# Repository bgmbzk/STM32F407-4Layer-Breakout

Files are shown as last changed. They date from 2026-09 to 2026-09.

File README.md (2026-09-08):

# STM32F407VGTx Yüksek Performanslı 4 Katmanlı PCB Geliştirme Kartı

Bu depo, **STM32F407VGT6** ARM Cortex-M4 mikrodenetleyicisi etrafında tasarlanmış, 4 katmanlı özgün bir basılı devre kartının (PCB) tasarım dosyalarını içermektedir.

Bu projenin temel amacı; gerçek zamanlı kontrol sistemleri, robotik uygulamalar ve yüksek kararlılık gerektiren gömülü sistem prototipleri için endüstriyel standartlarda, gürültüye dayanıklı ve güvenilir bir donanım platformu oluşturmaktır.

---

## Görseller

### 1. 3D Model Görünümü (3D Viewer)
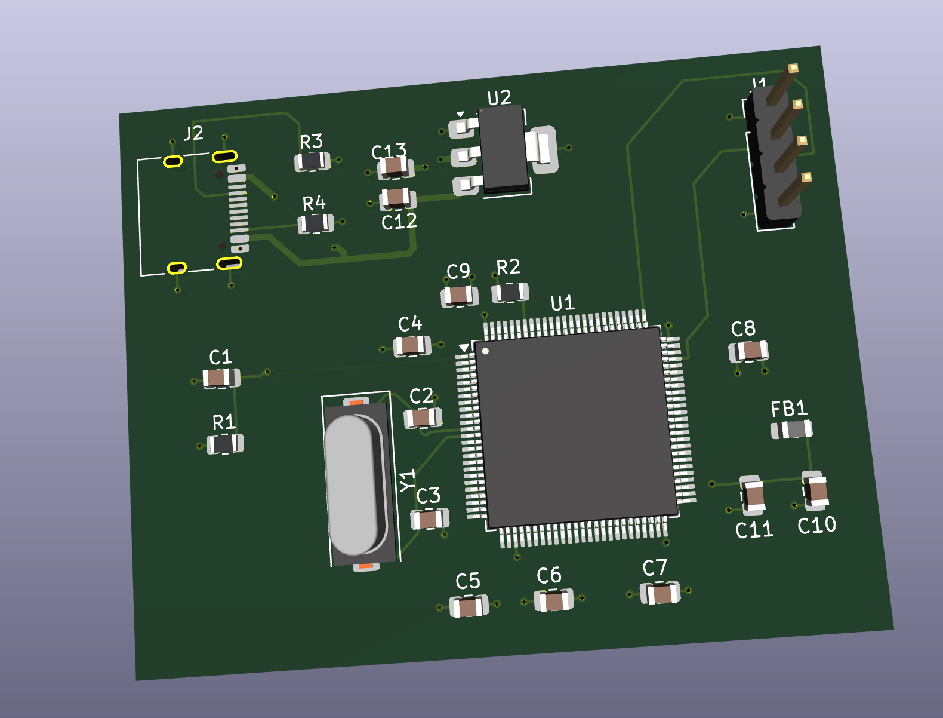
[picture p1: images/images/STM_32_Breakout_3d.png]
3D Kart Görünümü


### 2. PCB Tasarımı ve Katman Düzeni (PCB Layout)
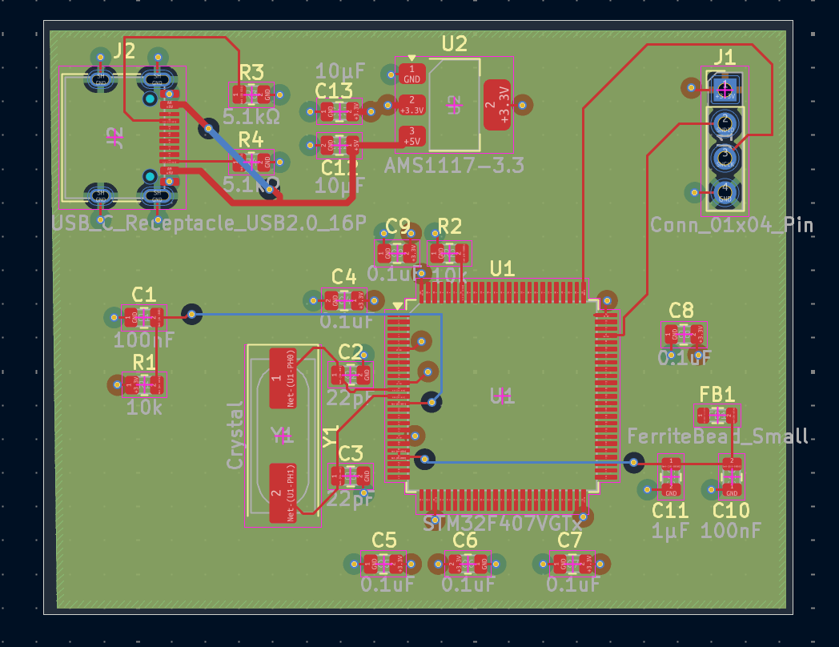
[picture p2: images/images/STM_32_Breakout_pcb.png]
PCB Katman Düzeni


### 3. Şematik Tasarım (Schematic Capture)
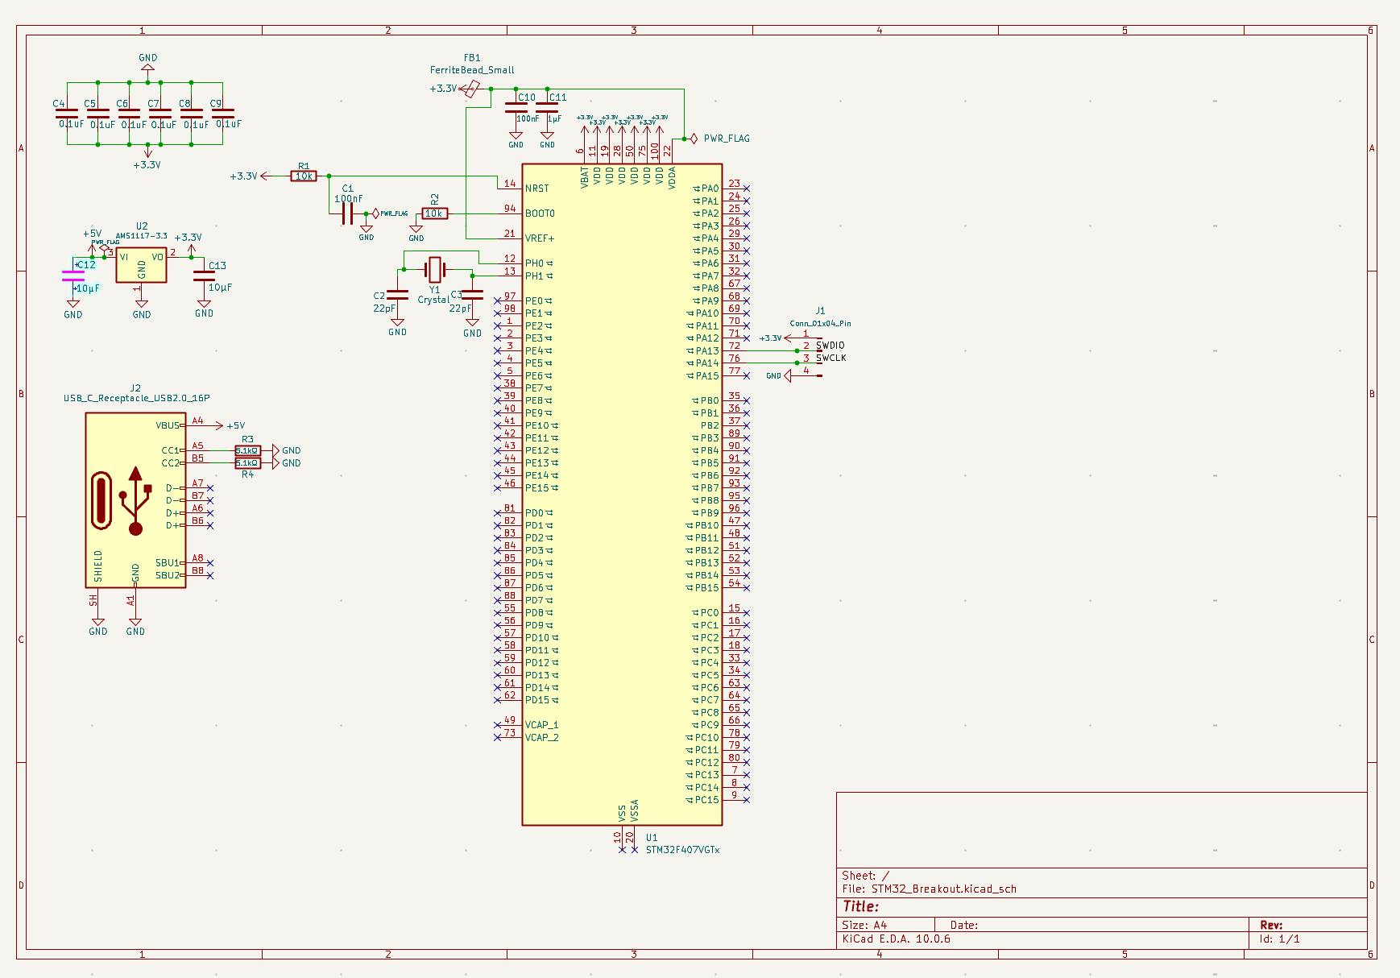
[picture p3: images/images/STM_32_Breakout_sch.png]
Şematik Diyagramı


---

## Donanım Mimarısı ve Öne Çıkan Özellikler

* **Mikrodenetleyici:** STM32F407VGT6 (168 MHz ARM Cortex-M4, Donanımsal FPU, 1 MB Flash, 192 KB RAM).
* **Güç Katı ve Regülasyon:** USB Type-C (+5V) girişi, LDO regülatörüne (AMS1117-3.3) girmeden önce C12 filtresinden geçirilerek filtrelenmiş ve kararlı bir +3.3V hat oluşturulmuştur.
* **Saat/Kristal Devresi:** Hassas sistem zamanlaması için empedans uyumlu ve kısa yollarla tasarlanmış Harici Yüksek Hızlı (HSE) kristal osilatör devresi.
* **Programlama ve Debug Arayüzü:** ST-Link ile kart üzerinde canlı hata ayıklama (Hardware In-Circuit Debugging) imkanı sunan 4 pinli SWD (Serial Wire Debug) konnektörü.
* **Bağlantı ve Koruma:** Şasi/GND koruma via'ları ile izole edilmiş ve paraziti önlenmiş USB 2.0 veri arayüzü.

---

## 4 Katmanlı PCB Stackup ve Güç İzolasyonu (Power Integrity)

Sinyal bütünlüğünü artırmak, elektromanyetik paraziti (EMI) en aza indirmek ve kararlı bir güç dağıtımı sağlamak amacıyla geleneksel 2 katmanlı tasarım yerine **4 katmanlı katman yapısı (stackup)** tercih edilmiştir:

1. **Üst Katman (`F.Cu`):** Yüksek hızlı sinyal hatları (Kristal, USB Veri hatları, SWD) ve bileşen bağlantıları.
2. **İç Katman 1 (`In1.Cu`):** Kesintisiz, düşük empedanslı dönüş yolları sağlayan özel **Toprak Düzlemi (GND Plane)**.
3. **İç Katman 2 (`In2.Cu`):** Düşük endüktanslı güç dağıtımı sağlayan özel **Güç Düzlemi (+3.3V Plane)**.
4. **Alt Katman (`B.Cu`):** İkincil sinyal hatları ve ek termal rahatlama alanı.

---

## Dosya Yapısı

```text
├── Hardware/
│   ├── STM32_Breakout.kicad_pcb    # KiCad PCB Çizim Dosyası
│   ├── STM32_Breakout.kicad_sch    # Şematik Çizim Dosyası
│   └── KiCad Proje Dosyaları
├── Fabrication/
│   ├── Gerbers/                     # Üretime Hazır Gerber Dosyaları
│   └── Drill/                       # Drill (Delik) Dosyaları
├── images/
│   ├── schematic.png                # Şematik Ekran Görüntüsü
│   ├── pcb_layout.png               # PCB Çizim Ekran Görüntüsü
│   └── pcb_3d.png                   # 3D Model Ekran Görüntüsü
└── README.md

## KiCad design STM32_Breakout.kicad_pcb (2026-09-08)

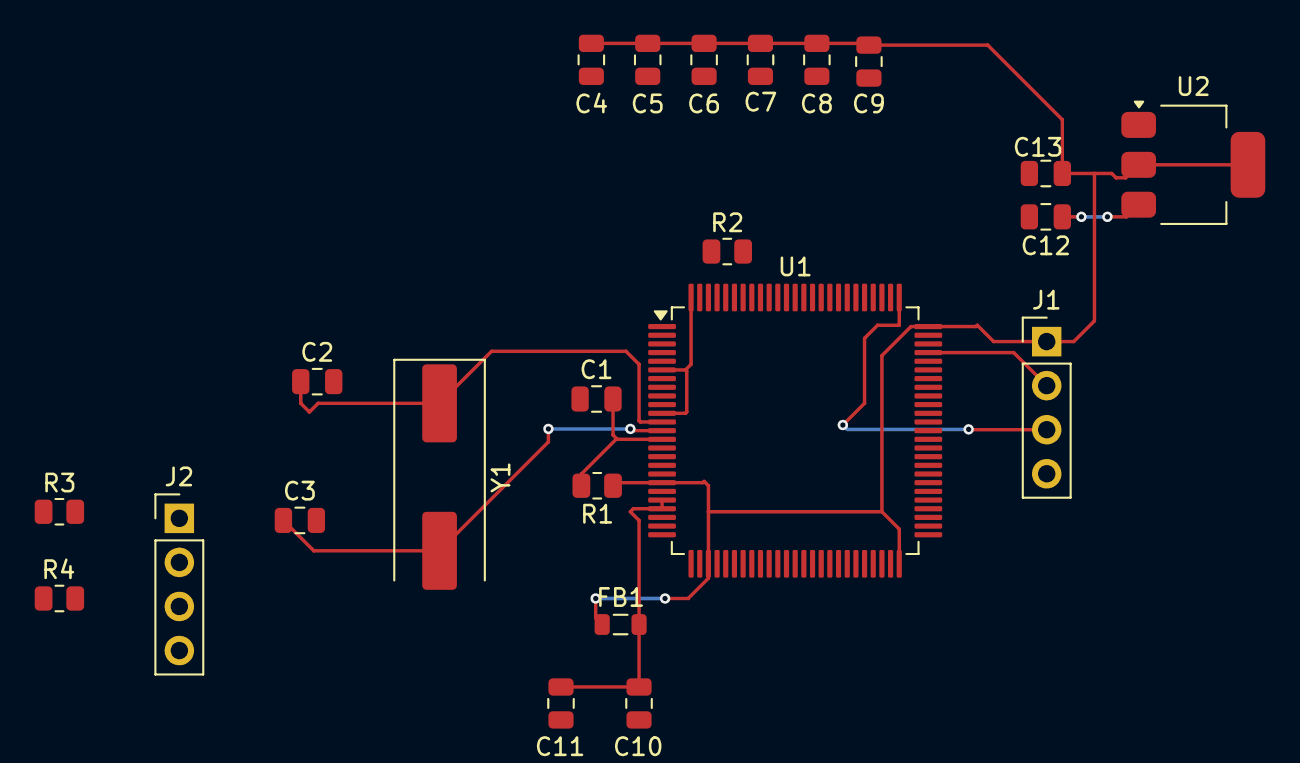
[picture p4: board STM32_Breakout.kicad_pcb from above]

Board: 2 copper layers, 23 parts (0 on the bottom side), 10 nets.

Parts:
C1, C10: 100nF; C_0805_2012Metric
C2, C3: 22pF; C_0805_2012Metric
C4, C5, C6, C7, C8, C9: 0.1uF; C_0805_2012Metric
C11: 1μF; C_0805_2012Metric
C12, C13: 10μF; C_0805_2012Metric
FB1: FerriteBead_Small; L_0805_2012Metric
J1: Conn_01x04_Pin; PinHeader_1x04_P2.54mm_Vertical
J2: USB_C_Receptacle_USB2.0_16P; PinHeader_1x04_P2.54mm_Vertical
R1, R2: 10k; R_0805_2012Metric
R3, R4: 5.1kΩ; R_0805_2012Metric
U1: STM32F407VGTx; LQFP-100_14x14mm_P0.5mm
U2: AMS1117-3.3; SOT-223-3_TabPin2
Y1: Crystal; Crystal_SMD_HC49-SD

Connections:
+3.3V: C4.1, C5.2, C6.2, C7.2, C8.2, C9.2, C13.2, FB1.1, J1.1, R1.1, U1.6 (VBAT), U1.11 (VDD), U1.19 (VDD), U1.28 (VDD), U1.50 (VDD), U1.75 (VDD), U1.100 (VDD), U2.2 (VO)
+5V: C12.1, U2.3 (VI)
/SWCLK: J1.3, U1.76 (PA14)
/SWDIO: J1.2, U1.72 (PA13)
GND: C1.1, C2.2, C3.2, C4.2, C5.1, C6.1, C7.1, C8.1, C9.1, C10.1, C11.2, C12.2, C13.1, J1.4, R2.1, R3.2, R4.2, U2.1 (GND)
unnamed: R2.2, U1.94 (BOOT0)
unnamed: C1.2, R1.2, U1.14 (NRST)
unnamed: C2.1, U1.12 (PH0), Y1.1
unnamed: C3.1, U1.13 (PH1), Y1.2
unnamed: C10.2, C11.1, FB1.2, U1.21 (VREF+), U1.22 (VDDA)
